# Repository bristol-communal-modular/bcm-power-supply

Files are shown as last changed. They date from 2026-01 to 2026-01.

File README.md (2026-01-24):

# BCM Power Supply

A basic eurorack power supply that can provide +12v, -12v, and +5v, at up to 1 Amp on each.

There are three PCBs here :-

* A power supply, that takes +15 volts and outputs +12v, -12v and +5v onto two eurorack power connectors
* A front panel that a DC jack and power indicator board can be mounted on
* A power indicator board that has LEDs for the three voltage rails

The power board is designed with four M3 holes in the corners, so it can be mounted into a case using stand-offs.

## Contact

Come down the Bristol Hackspace on a Tuesday night to say hello.

## License

This project is shared under an [Attribution-NonCommercial-ShareAlike 4.0 International License](https://creativecommons.org/licenses/by-nc-sa/4.0/)

This means that you can share the info here around, and transform or build upon the circuits and designs in here, as long as you share anything you do under the same license and give BCM a shout-out.

We don't license this for commercial purposes, but if you'd like to run a workshop with this or some variation of it, just get in contact and we can sort something out.
If you want to build a couple to sell to your mates then we're pretty fine with that as well.

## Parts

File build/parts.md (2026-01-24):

# Parts

Most of the components should be relatively easy to find (resistors, LEDs and capacitors for example) but a couple need to be specific.
This doc has links to the parts on a few websites, and some information about them that's worth bearing in mind when finding alternatives. NOTE: We've only sourced from Mouser, not from the other sites, but the parts *should* be the same.

## Regulators

N78 series regulators are used. The footprints on the PCB are designed for the enclosed version with a bend in the output pins so they sit flat on the board. The upright versions will work fine but will make the finished version taller which may be an issue depending on how much space there is in the case.

These parts are all the 2 Amp versions. There are apparently 1 Amp versions available which will probably be cheaper, but it doesn't seem possible to find them in the version that lies flat.

### 12V

N7812-2CH

[Mouser - 709-N7812-2CH](https://www.mouser.co.uk/ProductDetail/MEAN-WELL/N7812-2CH?qs=IKkN%2F947nfBns4sWKJt8PA%3D%3D)
[DigiKey - 1866-N7812-2CH-ND](https://www.digikey.com/en/products/detail/mean-well-usa-inc/N7812-2CH/24762172)
[Farnell - 4573217](https://uk.farnell.com/mean-well/n7812-2ch/dc-dc-converter-non-isolated-2a/dp/4573217)

### 5V

N7805-2CH

[Mouser - 709-N7805-2CH](https://www.mouser.co.uk/ProductDetail/MEAN-WELL/N7805-2CH?qs=IKkN%2F947nfA18hHQO%252BQQew%3D%3D)
[DigiKey - 1866-N7805-2CH-ND](https://www.digikey.com/en/products/detail/mean-well-usa-inc/N7805-2CH/24762182)
[Farnell - 4573207](https://uk.farnell.com/mean-well/n7805-2ch/dc-dc-converter-non-isolated-2a/dp/4573207)

## Inductors

The SN3-200 is specified for here, which is 10uH. It's chosen based on the values in the datasheet for the regulators, but it's worth noting it only has a maximum current of 1 Amp. There are larger inductors available, but the pitch on the footprint holes is only 5mm so some of them may not fit.
Will likely end up redesigning this with a different part, but it's fine for now.

SN3-200

[Mouser - 80-SN3-200](https://www.mouser.co.uk/ProductDetail/80-SN3-200)
[DigiKey - 399-20545-ND](https://www.digikey.com/en/products/detail/kemet/SN3-200/9955561?s=N4IgTCBcDaIM4DsDMBaMAGdIC6BfIA)
[Farnell - 2949420](https://uk.farnell.com/kemet/sn3-200/common-mode-choke-10uh-1a/dp/2949420)

## Fuse Holder

05200101Z by Littelfuse Inc.

None of the images on the websites is correct. There are just the metal parts without the plastic surround, and so two of them are needed, one for each end.

[Mouser - 576-05200101Z](https://www.mouser.co.uk/ProductDetail/576-05200101Z)
[DigiKey - F1504-ND](https://www.digikey.com/en/products/detail/littelfuse-inc/05200101Z/554336)
[Farnell - 1608232](https://uk.farnell.com/littelfuse/05200101z/fuseholder-2x20mm/dp/1608232)

## Terminal blocks

The build uses the version from Phoenix Contact, which is a well known brand. There may be other, cheaper alternatives though.
Also you could go without these and just solder wires directly from the DC Jack to the PCB if you want.

[Mouser - 651-1715022](https://www.mouser.co.uk/ProductDetail/651-1715022)
[DigiKey - 277-1258-ND](https://www.digikey.com/en/products/detail/phoenix-contact/1715022/260626)
[Farnell - 3714240](https://uk.farnell.com/phoenix-contact/mkds-1-5-2/terminal-block-wire-to-brd-2pos/dp/3714240)

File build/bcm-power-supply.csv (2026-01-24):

Id | Designator | Footprint | Quantity | Designation | Supplier and ref
1 | R3,R2 | R_Axial_DIN0207_L6.3mm_D2.5mm_P10.16mm_Horizontal | 2 | 10k
2 | U3 | TO-220-3_Horizontal_TabDown | 1 | N7805
3 | F1 | Fuseholder_Clip-5x20mm_Littelfuse_520_Inline_P20.50x5.80mm_D1.30mm_Horizontal | 1 | Fuse
4 | J1 | TerminalBlock_Phoenix_MKDS-1,5-2-5.08_1x02_P5.08mm_Horizontal | 1 | Screw_Terminal_01x02
5 | D3,D5,D2,D4 | LED_D3.0mm | 4 | LED
6 | R1 | R_Axial_DIN0207_L6.3mm_D2.5mm_P10.16mm_Horizontal | 1 | 20k
7 | C3,C6,C4 | CP_Radial_D6.3mm_P2.50mm | 3 | 22uF
8 | R4 | R_Axial_DIN0207_L6.3mm_D2.5mm_P10.16mm_Horizontal | 1 | 4k7
9 | L1,L2 | L_Toroid_Vertical_L10.0mm_W5.0mm_P5.08mm | 2 | 10uH
10 | U1,U2 | TO-220-3_Horizontal_TabDown | 2 | N7812
11 | C2,C1,C5 | CP_Radial_D6.3mm_P2.50mm | 3 | 10uF
12 | J2,J3 | Eurorack_Power_IDC-Header_2x08_P2.54mm_Vertical | 2 | Conn_02x08_Odd_Even
13 | D1 | D_DO-41_SOD81_P10.16mm_Horizontal | 1 | 1N5818

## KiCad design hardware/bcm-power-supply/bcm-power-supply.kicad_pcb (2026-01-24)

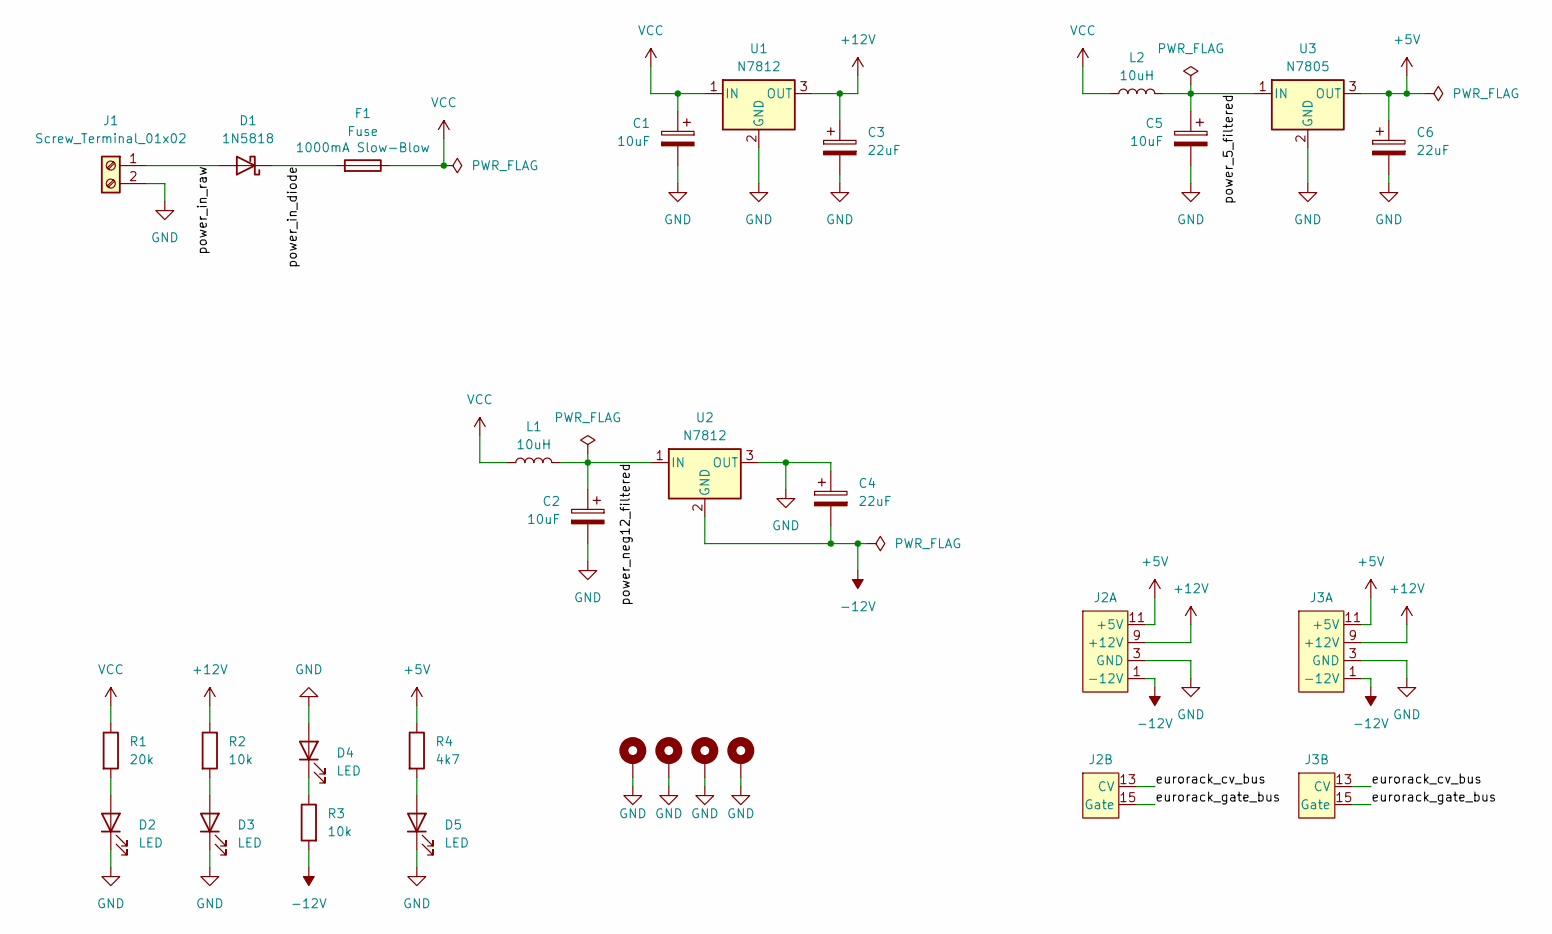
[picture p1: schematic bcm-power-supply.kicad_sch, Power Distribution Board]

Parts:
C1, C2, C5: 10uF; CP_Radial_D6.3mm_P2.50mm; Voltage 50V
C3, C4, C6: 22uF; CP_Radial_D6.3mm_P2.50mm; Voltage 50V
D1: 1N5818; D_DO-41_SOD81_P10.16mm_Horizontal
D2, D3, D4, D5: LED; LED_D3.0mm
F1: Fuse; Fuseholder_Clip-5x20mm_Littelfuse_520_Inline_P20.50x5.80mm_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
H1, H2, H3, H4: MountingHole_Pad; MountingHole_3.2mm_M3_DIN965_Pad
J1: Screw_Terminal_01x02; TerminalBlock_Phoenix_MKDS-1,5-2-5.08_1x02_P5.08mm_Horizont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; MPN 1715022
J2, J3: Conn_02x08_Odd_Even; Eurorack_Power_IDC-Header_2x08_P2.54mm_Vertical
L1, L2: 10uH; L_Toroid_Vertical_L10.0mm_W5.0mm_P5.08mm; MPN SN3-200
R1: 20k; R_Axial_DIN0207_L6.3mm_D2.5mm_P10.16mm_Horizontal; Tolerance 1%
R2, R3: 10k; R_Axial_DIN0207_L6.3mm_D2.5mm_P10.16mm_Horizontal; Tolerance 1%
R4: 4k7; R_Axial_DIN0207_L6.3mm_D2.5mm_P10.16mm_Horizontal; Tolerance 1%
U1, U2: N7812; TO-220-3_Horizontal_TabDown
U3: N7805; TO-220-3_Horizontal_TabDown

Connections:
+5V: C6.1, J2.11 (+5V), J2.12 (+5V), J3.11 (+5V), J3.12 (+5V), R4.1, U3.3 (OUT)
+12V: C3.1, J2.9 (+12V), J2.10 (+12V), J3.9 (+12V), J3.10 (+12V), R2.1, U1.3 (OUT)
-12V: C4.2, J2.1 (-12V), J2.2 (-12V), J3.1 (-12V), J3.2 (-12V), R3.2, U2.2 (GND)
/eurorack_cv_bus: J2.13 (CV), J2.14 (CV), J3.13 (CV), J3.14 (CV)
/eurorack_gate_bus: J2.15 (Gate), J2.16 (Gate), J3.15 (Gate), J3.16 (Gate)
/power_5_filtered: C5.1, L2.2, U3.1 (IN)
/power_in_diode: D1.1 (K), F1.2
/power_in_raw: D1.2 (A), J1.1
/power_neg12_filtered: C2.1, L1.2, U2.1 (IN)
GND: C1.2, C2.2, C3.2, C4.1, C5.2, C6.2, D2.1 (K), D3.1 (K), D4.2 (A), D5.1 (K), H1.1, H2.1, H3.1, H4.1, J1.2, J2.3 (GND), J2.4 (GND), J2.5 (GND), J2.6 (GND), J2.7 (GND), J2.8 (GND), J3.3 (GND), J3.4 (GND), J3.5 (GND), J3.6 (GND), J3.7 (GND), J3.8 (GND), U1.2 (GND), U2.3 (OUT), U3.2 (GND)
unnamed: D2.2 (A), R1.2
unnamed: D3.2 (A), R2.2
unnamed: D4.1 (K), R3.1
unnamed: D5.2 (A), R4.2
VCC: C1.1, F1.1, L1.1, L2.1, R1.1, U1.1 (IN)

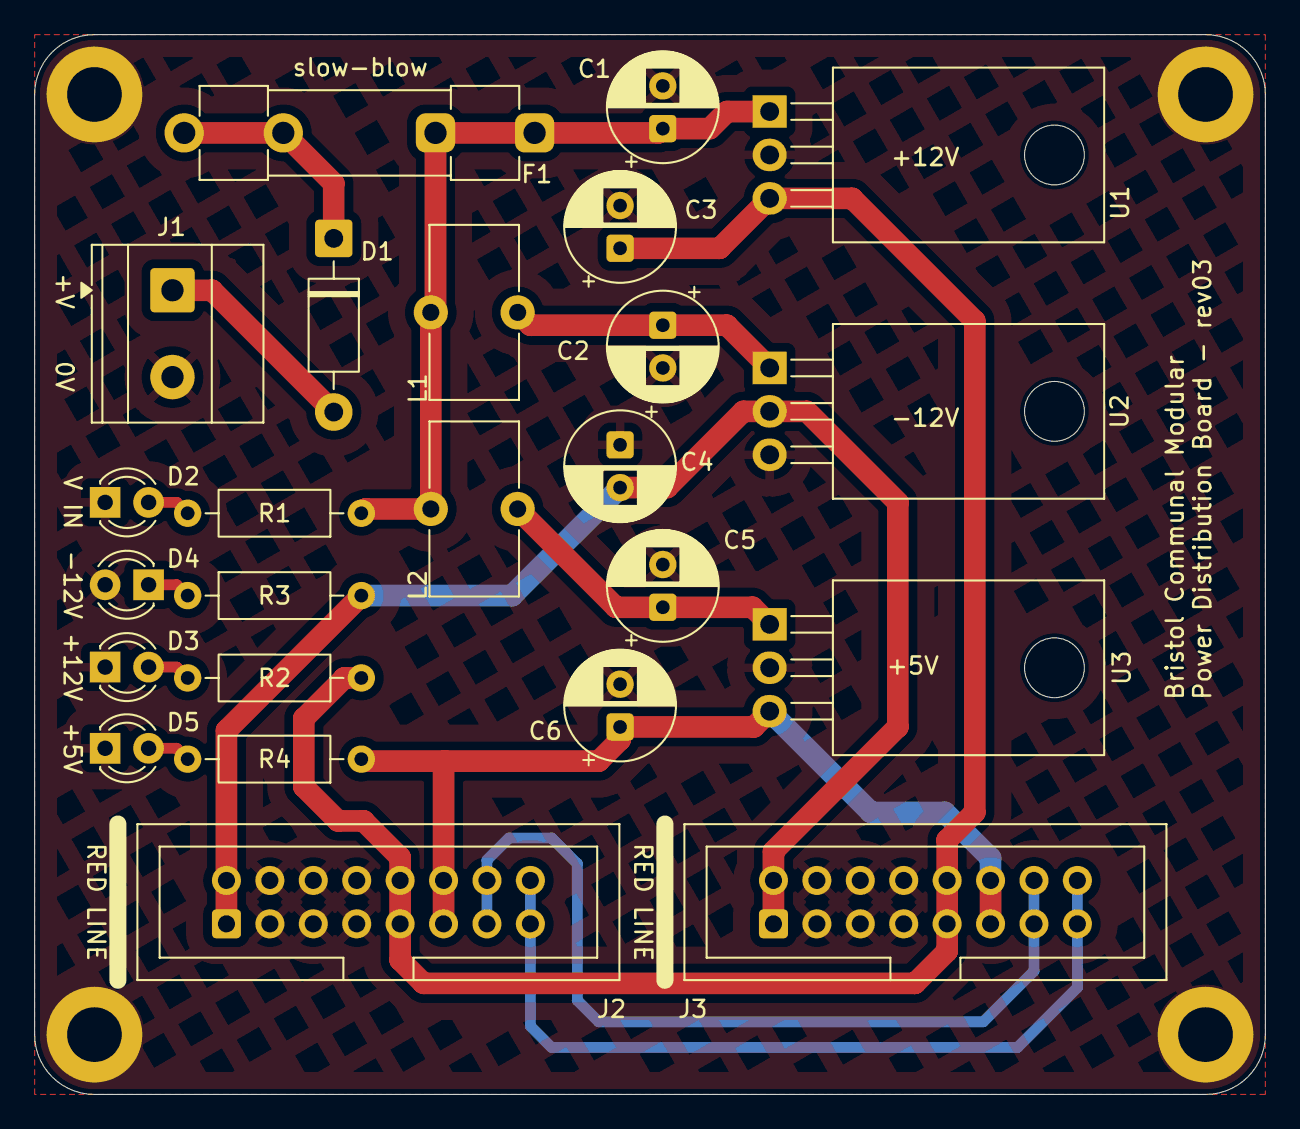
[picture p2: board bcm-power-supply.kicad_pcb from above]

Board: 2 copper layers, 72.0 x 62.0 mm, 29 parts (1 on the bottom side), 15 nets.

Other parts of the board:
Ref**: Val**; BCM_Logo_small_15mmx15mm

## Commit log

2026-01-03 Updating with 5v output
    And making the board smaller
    [bcm-power-supply-B_Cu.gbl, bcm-power-supply-B_Mask.gbs, bcm-power-supply-B_Silkscreen.gbo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]
2026-01-03 Moving gerber files
    [bcm-power-supply-B_Cu.gbl, bcm-power-supply-B_Mask.gbs, bcm-power-supply-B_Silkscreen.gbo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]
2026-01-03 Adding input panel
    [input-panel-B_Cu.gbl, input-panel-B_Mask.gbs, input-panel-B_Silkscreen.gbo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]
2026-01-24 Updating power supply board to give more space for regulators
    [bcm-power-supply-B_Cu.gbl, bcm-power-supply-B_Mask.gbs, bcm-power-supply-B_Silkscreen.gbo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]
2026-01-24 Adding build info
    [bcm-power-supply.csv]

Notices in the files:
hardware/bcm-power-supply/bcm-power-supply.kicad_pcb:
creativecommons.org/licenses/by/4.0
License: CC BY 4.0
